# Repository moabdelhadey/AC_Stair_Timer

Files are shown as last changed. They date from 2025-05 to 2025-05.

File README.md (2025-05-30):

# AC Stair Timer (High-Load AC Triggered Timer Circuit using NE555)

An affordable and energy-efficient timer circuit designed to control stairway lighting. The circuit is triggered by an AC signal from any stair switch and automatically turns off the light after a user-defined delay. It consumes **no power while idle**, thanks to a latch mechanism that cuts off the entire supply when the relay opens.

---

## ✅ Features

- **AC Triggered**: Can be triggered from any AC switch connected in the stairway.
- **Zero Power Consumption in Standby**: Power supply is wired in series with the load. Once the relay disconnects the load, the entire circuit powers off.
- **Handles up to 10A Load**: Suitable for high-power lighting circuits.
- **Adjustable Timer (0–15 min)**: Controlled by a potentiometer. Can be extended using standard NE555 timing calculations.
- **Low-Cost and Simple Components**: Built around NE555, a relay, and basic resistors/capacitors.
- **Single-Layer PCB**: Easy for home etching or low-cost fabrication.
- **Local Alternative to Imported Units**: Provides the same functionality at a fraction of the cost.

---

## 🧩 Main Components

- NE555 Timer IC
- Relay (10A rated)
- Potentiometer
- Capacitors and resistors

---

## ⏱️ Time Adjustment Formula

You can calculate or extend the timing duration using the standard NE555 monostable formula:

```
T ≈ 1.1 × R × C
```

Where:
- `R` is the potentiometer (resistance in ohms)
- `C` is the timing capacitor (in farads)

---

## 📁 Project Files

- **KiCad** design files (schematic + PCB layout)
- **Proteus** simulation file
- **STEP file** (3D model of assembled circuit)
- **PDFs** for manual PCB etching (Top layer, Drill, Silkscreen)
- Real-life **assembly images**

---

## 🧪 Project Status

- ✅ **Version 1** tested successfully in a real stairway.
- 🛠️ **Version 2** in development with enhancements.

---

## ⚠️ Safety Notes

- Ensure proper isolation when connecting to AC.
- Add relay cooling if switching high loads frequently.

---

## 📜 License

This project is open source.

---

## 📷 Images

---

## 📬 Contact

Mohamed Abdelhady — For inquiries, feel free to reach out if any issue arises.

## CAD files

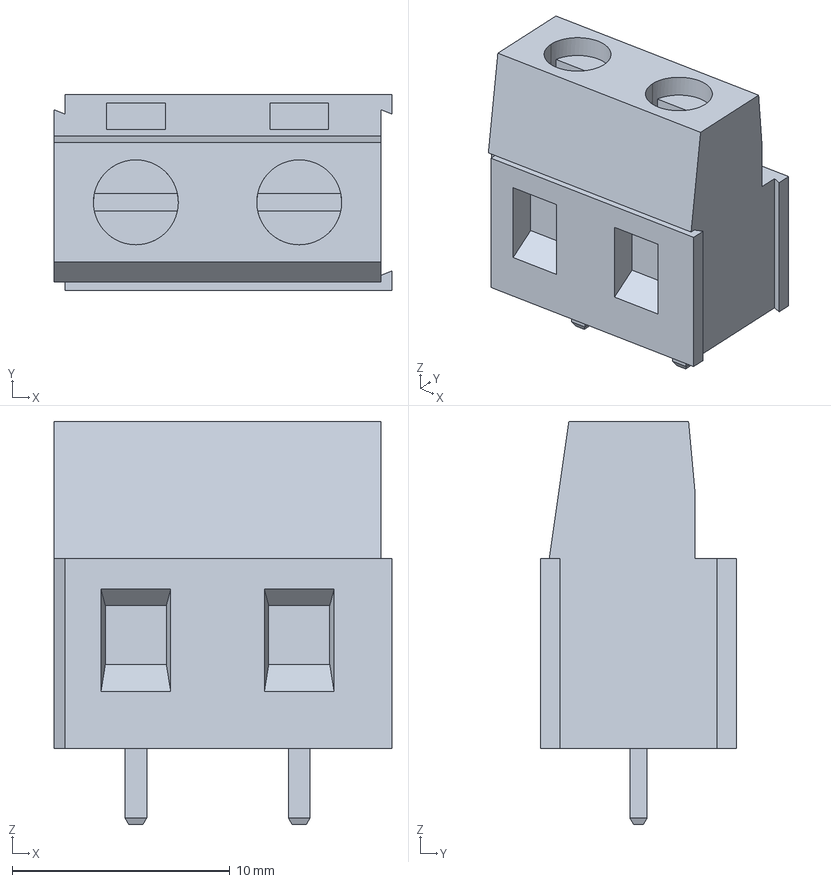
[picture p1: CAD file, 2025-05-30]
3D_files/terminal_block.stp
15.5 x 9.00 x 18.5 mm

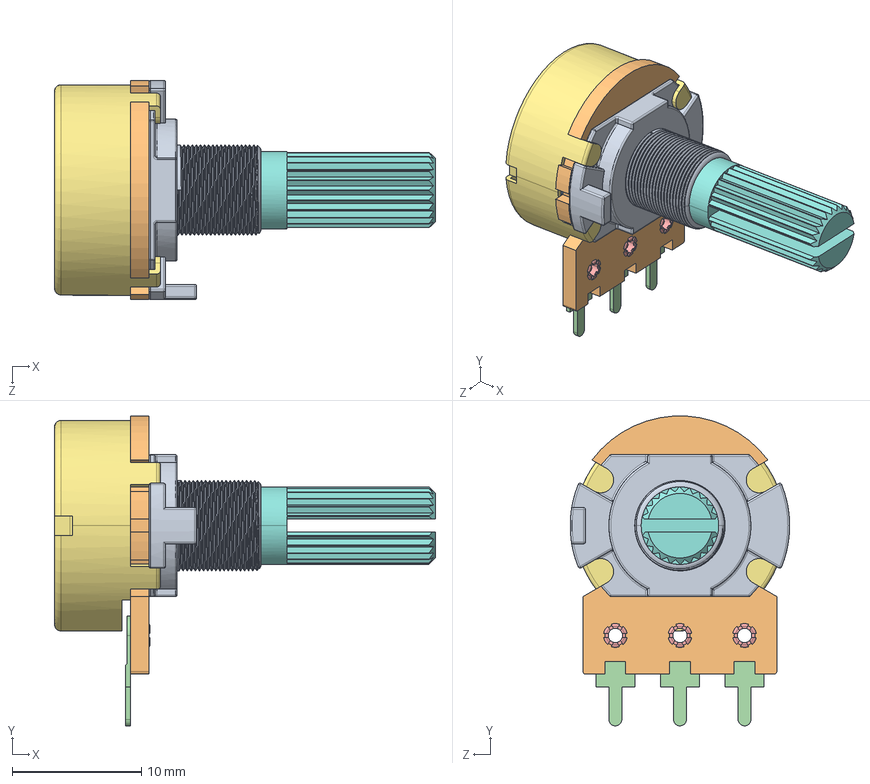
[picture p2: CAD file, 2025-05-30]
3D_files/potentiometer.step
29.5 x 24.0 x 17.0 mm
PTN16_1 BUSHING
PTN16-A_1 HOUSING
PTN16_20K1_SHAFT

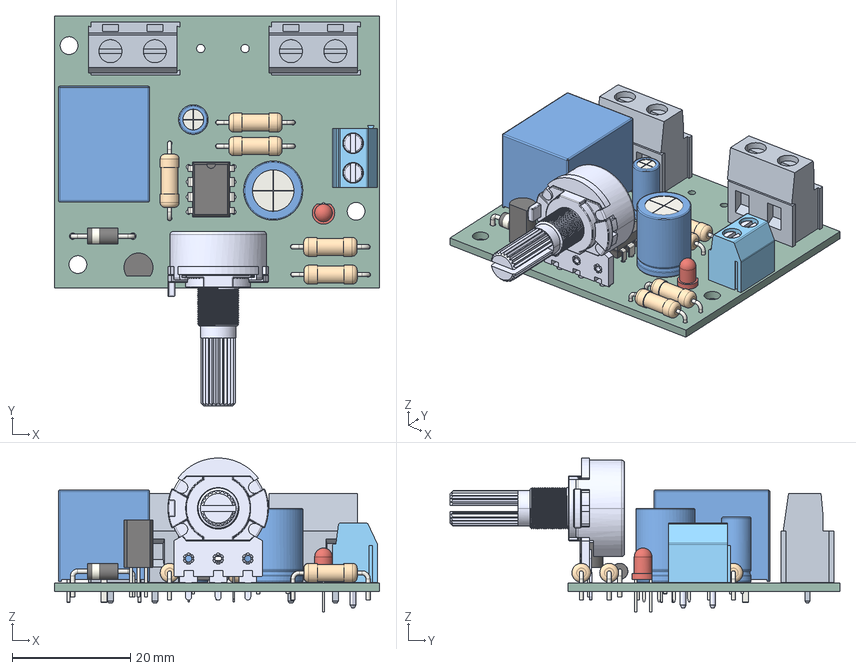
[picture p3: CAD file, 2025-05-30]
3D_files/PCB.step
55.0 x 65.9 x 26.0 mm
R_Axial_DIN0309_L9.0mm_D3.2mm_P12.70mm_Horizontal x 5
LED_D3.0mm
PTN16_1 BUSHING
PTN16-A_1 HOUSING
PTN16_20K1_SHAFT
Relay_SPDT_SANYOU_SRD_Series_Form_C
TB002-500-02P_Blue - S
D_DO-41_SOD81_P10.16mm_Horizontal
terminal_block x 2
TO-92L_Inline
C_Radial_D5.0mm_H11.0mm_P2.00mm
DIP-8_W7.62mm
C_Radial_D10.0mm_H12.5mm_P5.00mm
timer_circuit_PCB

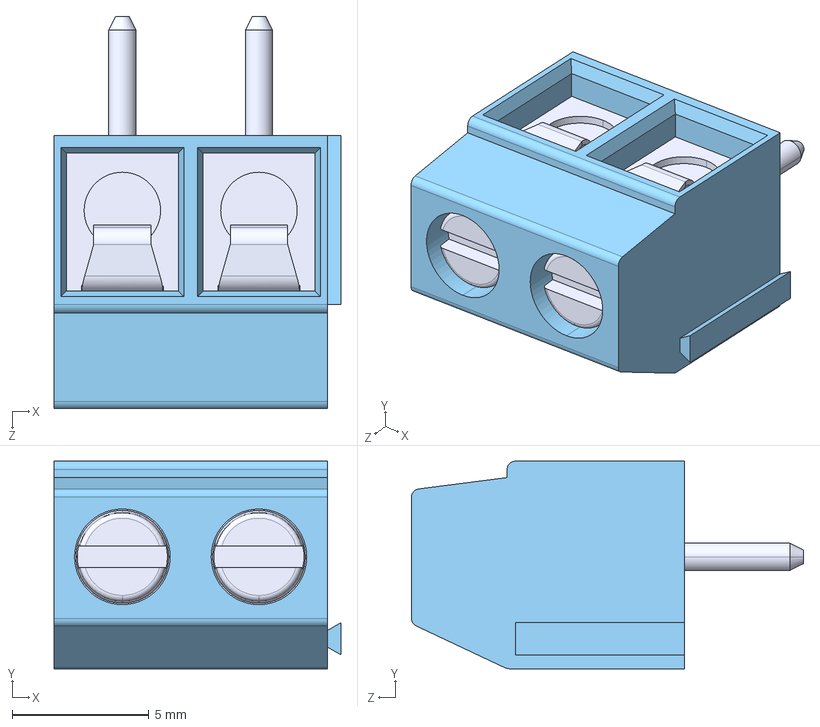
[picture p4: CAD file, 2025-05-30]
3D_files/Same_Sky_TB002-500-02BE.step
10.5 x 7.60 x 14.4 mm

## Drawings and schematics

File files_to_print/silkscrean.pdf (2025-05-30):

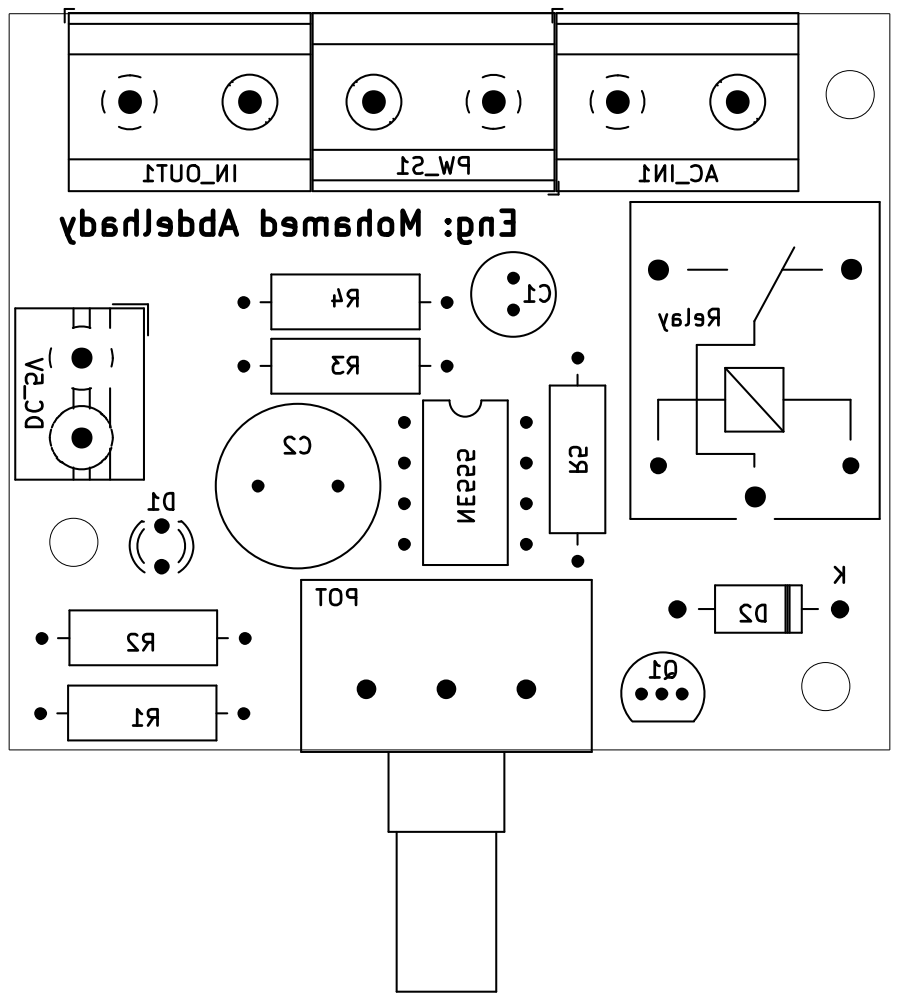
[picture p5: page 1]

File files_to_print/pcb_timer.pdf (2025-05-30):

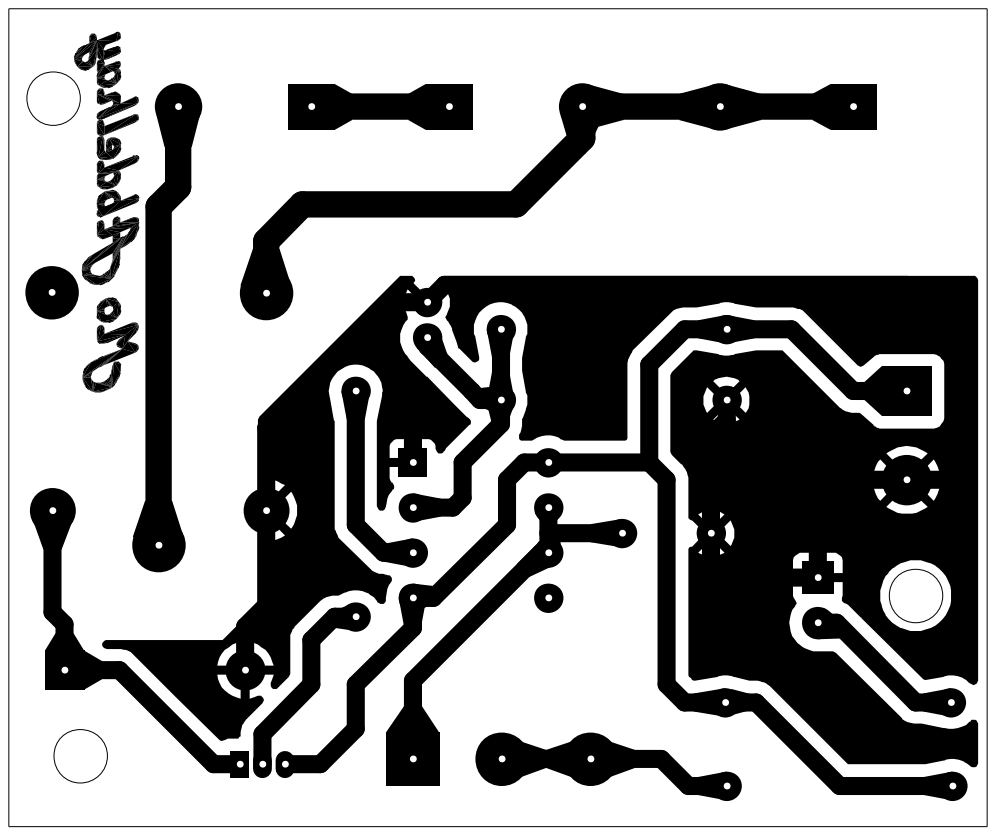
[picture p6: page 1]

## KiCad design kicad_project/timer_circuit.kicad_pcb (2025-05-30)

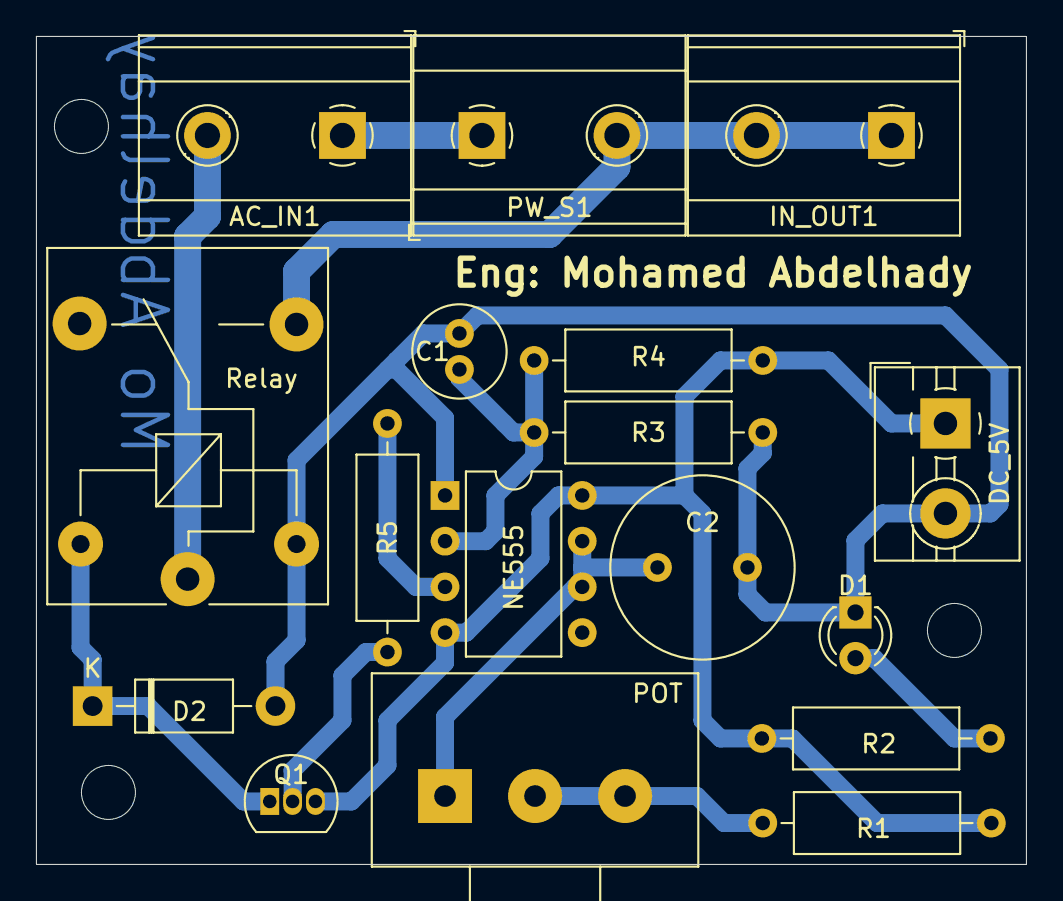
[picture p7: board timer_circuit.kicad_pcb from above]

Board: 2 copper layers, 55.0 x 46.0 mm, 17 parts (0 on the bottom side), 12 nets.

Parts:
AC_IN1: Screw_Terminal_01x02; TerminalBlock_MetzConnect_Type175_RT02702HBLC_1x02_P7.50mm_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
C1: 1uF; C_Radial_D5.0mm_H11.0mm_P2.00mm
C2: 470uF; C_Radial_D10.0mm_H12.5mm_P5.00mm
D1: LED; LED_D3.0mm
D2: 1N4007; D_DO-41_SOD81_P10.16mm_Horizontal
DC_5V: Screw_Terminal_01x02; TerminalBlock_MaiXu_MX126-5.0-02P_1x02_P5.00mm
IN_OUT1: Screw_Terminal_01x02; TerminalBlock_MetzConnect_Type175_RT02702HBLC_1x02_P7.50mm_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
NE555: NE555P; DIP-8_W7.62mm
POT: R_Potentiometer; Potentiometer_Alps_RK163_Single_Horizontal
PW_S1: Screw_Terminal_01x02; TerminalBlock_MetzConnect_Type175_RT02702HBLC_1x02_P7.50mm_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
Q1: 2N3904; TO-92L_Inline
R1, R3: 100K; R_Axial_DIN0309_L9.0mm_D3.2mm_P12.70mm_Horizontal
R2: 220R; R_Axial_DIN0309_L9.0mm_D3.2mm_P12.70mm_Horizontal
R4: 10K; R_Axial_DIN0309_L9.0mm_D3.2mm_P12.70mm_Horizontal
R5: 500R; R_Axial_DIN0309_L9.0mm_D3.2mm_P12.70mm_Horizontal
Relay: 5V; Relay_SPDT_SANYOU_SRD_Series_Form_C

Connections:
GND: C1.2, C2.2, D1.1 (K), D2.2 (A), DC_5V.2, NE555.1 (GND), R3.1, Relay.2
unnamed: AC_IN1.1, PW_S1.1
unnamed: AC_IN1.2, Relay.1
unnamed: D1.2 (A), R2.1
unnamed: D2.1 (K), Q1.1 (E), Relay.5
unnamed: IN_OUT1.1, IN_OUT1.2, PW_S1.2, Relay.3
unnamed: Q1.2 (B), R5.2
unnamed: POT.2, POT.3, R1.1
unnamed: C2.1, NE555.6 (THR), NE555.7 (DIS), POT.1
unnamed: NE555.3 (Q), R5.1
unnamed: C1.1, NE555.2 (TR), R3.2, R4.2
VCC: DC_5V.1, NE555.4 (R), NE555.8 (VCC), Q1.3 (C), R1.2, R2.2, R4.1
